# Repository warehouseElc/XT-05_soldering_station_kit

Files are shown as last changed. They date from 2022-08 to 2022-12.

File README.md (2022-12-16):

# XT-05 Soldering station kit
5 in 1 Soldering Rework Station "NOT Unisolder"

<p align="center">
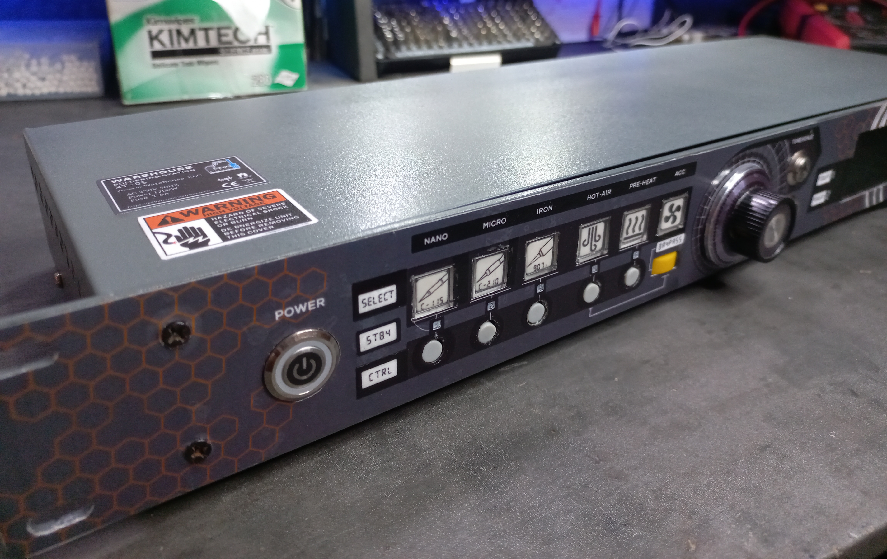
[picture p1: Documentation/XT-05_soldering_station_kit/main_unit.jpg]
  
</p> 

This project come for DIYers to make a good and reliable soldering station kit.
it works as independent controller, 
that's mean you can't swap the tip each other like unisolder cause it doesn't have a tip preset.
this come to much complexity for cable management, since i design it to be fully modular.
so... no solder required to disassamble whole unit.
all firmware not originaly made by me, but it's a lot of effort to modded and bugfixes.
if you want to copy or modified any of this resource, 
please let me know the result of your work.
this controller is still upgradable, but i dont have enough time to made this full of feature.

<p align="center">
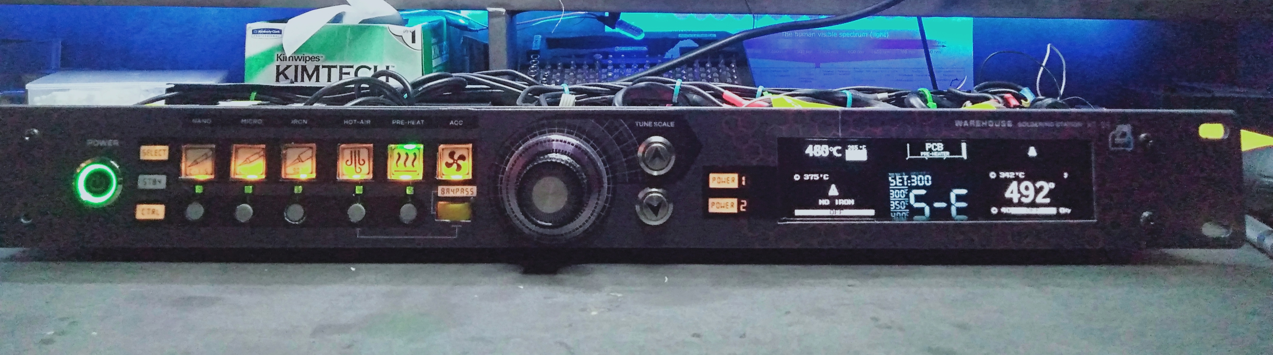
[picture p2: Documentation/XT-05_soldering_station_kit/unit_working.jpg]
  
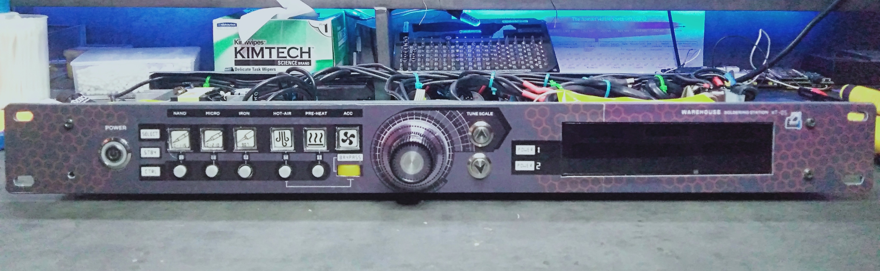
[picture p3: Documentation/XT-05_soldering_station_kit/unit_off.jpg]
  
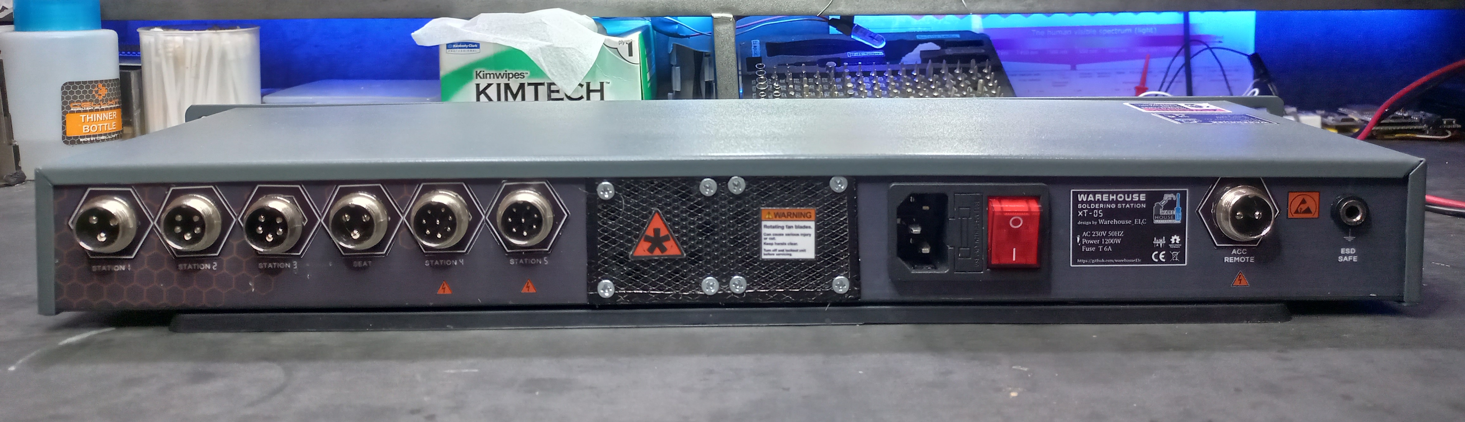
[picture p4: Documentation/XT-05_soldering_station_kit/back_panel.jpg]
  
</p> 

# Main Unit :
  * This unit controlled by atmega328p mount at FrontPanel board, it use I/O to select which controller you wanna uses and activated independent optocoupler for each controller and each signal.
  * ACC remote to turn on acc like fume extractor or etc by push a software latch button.
  * it's also come with one encoder and 2 button to operate the controller.
  * the CTRL switch operated directly to main controller power.
  * when push up & down button at the same time it will lock the I/O.
  * after 2 hour at Lock mode the unit goes to stby mode by switch off the relay main 5v & 12v , as indicator STBY turn green.
  * baypass mode working just for Hotair station.
  * an ESD plug was separated by main groung / AC earth socket.
    
<p align="center">
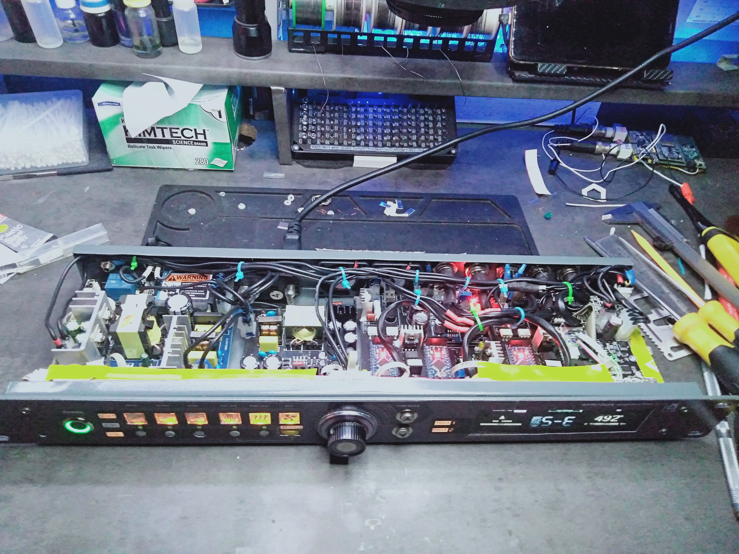
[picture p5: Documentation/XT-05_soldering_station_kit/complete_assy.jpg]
  
</p> 

<p align="center">
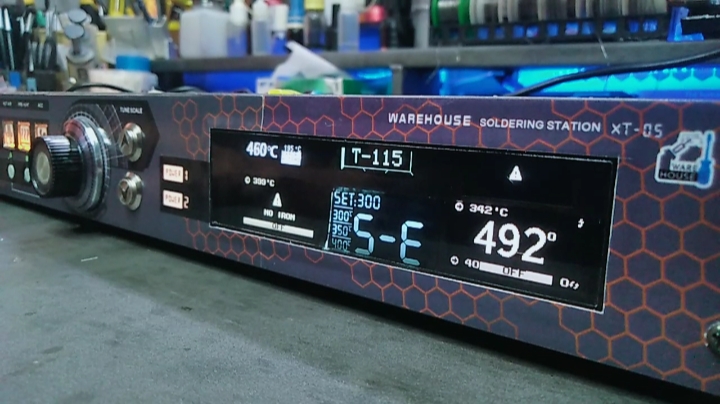
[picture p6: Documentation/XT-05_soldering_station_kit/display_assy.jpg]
  
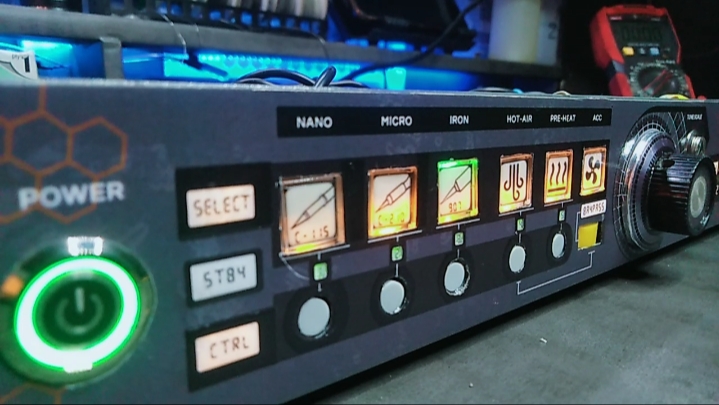
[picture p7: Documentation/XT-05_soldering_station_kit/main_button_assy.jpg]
  
</p> 

# This controller contains :

1. Nano solder NT-115.
   this controller use stm32f030f4 work at max 18v supply but the tip it self consume just 15w at 9v.
   i used 12v supply for this and calibrated it for chinese tip. if you want to use jbc original or diffrent vendor you just need re-calibrated it.
     
     Feature : 
     
       * can be use with any c-115 handle or tips.
       * sleep seat.
       * stable & fast respond time.
       * small PCB dimension.
       * less component
       * voltage supply, 3v3 & temp measurment.
       * calibrated menu.
       * error hi/lo-Temp, hi/lo-volt detection.
       
     Known Bug :
       
       * No buzzer/bepper
       * input supply must stable & avoid get voltage spike.
       * using medium-high cost & almost at rare status by now of component.
       * "dont cut" any 3v3 input since it use low-side mosfet it will directly supply 12v to the tip if 3v3 not coming.
       * need some protection if 12v on standby but 3v3 not coming.
       * encoder issue with some incompatible devices.
       * open 3v coming from the seat need more attention. "dont swap with Microsolder seat" 
       
2. Micro solder T-210.
   This controller still use Chinese GVM stc32. in future we can adapt NT-115 controller work for c-210 tip, but !!!
   i need more time to fix a bug and test it.
       
      Feature :
       
        * do i need to explain it ? i dont thing so.

3. iron solder hakko 9series.
    This controller use atmega328p (promini), and run at DC 24v very smoothly.
      
      Feature :
      
        * Tune & Calibrated Menu
        * error screen.
        * easy to use and interactive display.
        * isolated to main power.
        
      Known Bug :
      
        * hard to calibrate cause by slow reading.
        * auto sleep sometimes not working.
        * noisy at heater when start up.
        * no preset temp.
        
4. Hotair 858D.
    This controller use atmega328p (promini), with 700w 220v heater element.
      
      Feature :
      
        * Tune & Calibrated Menu
        * error screen.
        * easy to use and interactive display.
        * add bypass mode to active cool air.
        * isolated to main power
        
      Known Bug :
      
        * hard to calibrate cause by slow reading.
        * seat sleep is lag by 3second.
        * sometimes display get stuck.
        * no preset temp.
        
5. Pre-heater.
   This controller use atmega328p (promini), with 200w/400w 220v heater element.
   (based on Hotair station firmware).
   
      Feature :
      
        * Tune & Calibrated Menu
        * error screen.
        * easy to use and interactive display.
        * isolated to main power

      Known Bug :
      
        * hard to calibrate cause by slow reading.
        * very slow respond.
        * no preset temp.

# Technical Image.
<p align="center">
  hover text
</p> 
<p align="center">
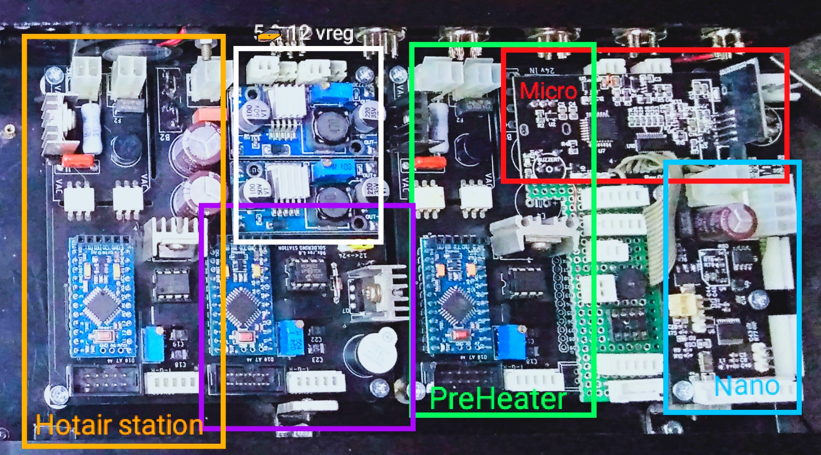
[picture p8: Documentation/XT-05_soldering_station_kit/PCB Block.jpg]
  
</p> 
<p align="center">
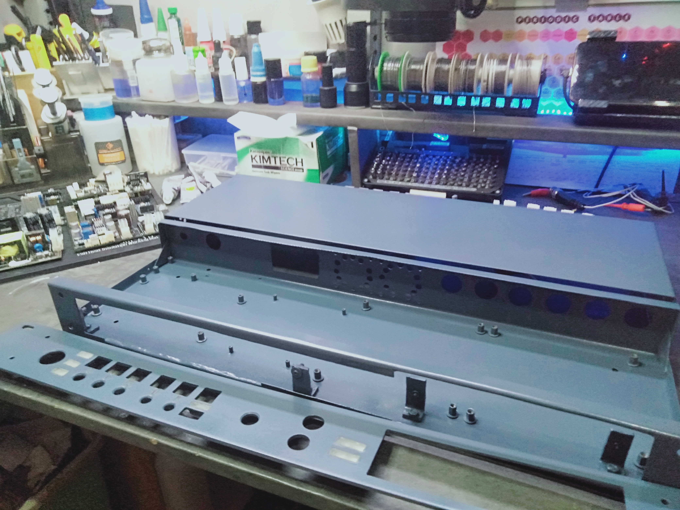
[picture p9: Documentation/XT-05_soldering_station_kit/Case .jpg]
  
</p> 
<p align="center">
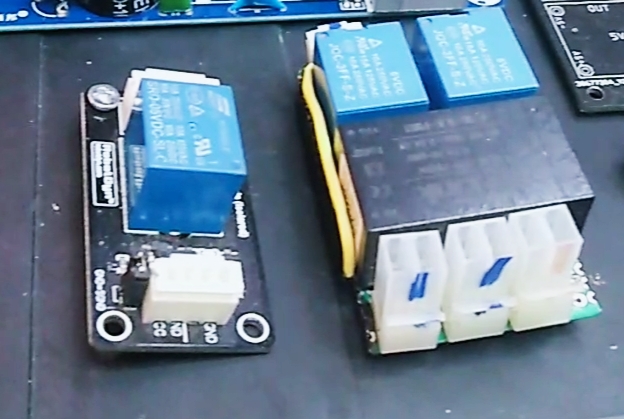
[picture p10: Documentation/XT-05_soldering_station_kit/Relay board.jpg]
  
</p> 
<p align="center">
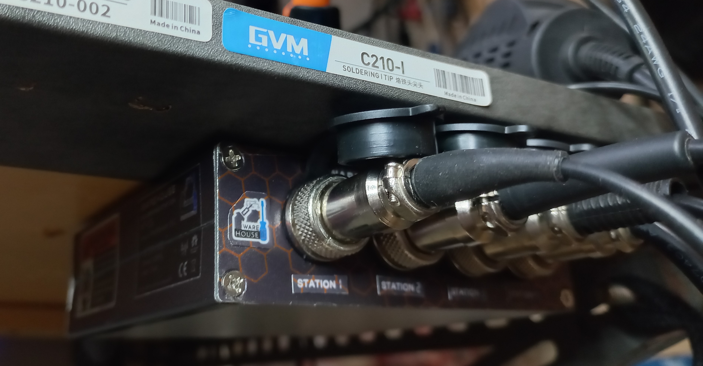
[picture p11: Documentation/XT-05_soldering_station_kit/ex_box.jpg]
  
</p> 

# Test Method :
  * it was 2 years testing by daily workflow until now no magic smoke no fire and no overheat.
  * all controller was test individual function without problem.
  * under heavy load still no problem.
  * unstable main VAC doesn't cause any issue.
  * working almost at 30c room temp no aircond everyday use.
  * standby more than 5 hour everyday.

# Progress on 2023 :
  * get some data by measure at maximum load
  * testing c210 on nano controller.
  * hardware & software bug fixes.
  * make some improvement.
  * added more protection.

# ChangeLog : 

  (2022)
  Firmware 9series v.2.1 Hotair v.1.5 PreHeater v.1.0 (Board v4.0) Nanosolder v.1.2 (Board v.1.1) F.panel v.1.2.1 (Board v.1.4.0) 
  
    * Put all controller in a 1u case.
    * add two extra button as simulated encoder output @10ms using FP_MCU.
    * using 2 PSU, 24v for iron,hotair,Preheater, 12v for nano & micro.
    * output can be use with extention box or just plug to main unit.
    * modified some powerline for controlling using FP_MCU.
        * 2 Relay add to main 220v control directly with power button
        * add relay module for ACC remote.
        * 2 Relay add for 5vreg & 12v main.
   
  (2021)
  Firmware 9series v.2.1 Hotair v.1.5 (Board Version 4.0) 
  
    * change component to SMD as possible
    * SH1106 Oled 1.3" Used For Display
    * Removing class PIDscreen for Hot Air to free some memory
    * Protection on Board
    * thermocouple / Thermoresistor Select on board
    * Fan 24/12volt select on board
    * Custom Front Panel for operated just only 1 encoder, I/O via IDC Socket

# Resource :
  This Project is Upgrade Version from Original.
   * Iron : https://create.arduino.cc/projecthub/sfrwmaker/soldering-iron-controller-for-hakko-907-v-2-fc75d7
   * Nano : https://github.com/Winkelkatze/jbc_nano_solder
   * Hotair & Preheater : https://www.hackster.io/makerbr555/diy-smd-rework-station-28b6f5

# first test of Board v3.0
https://www.youtube.com/watch?v=hSPyxu3pc1E

# first test of Board v4.0
https://youtu.be/PgkWCMdGw-8

# first test of full build (New Firmware)
coming soon...

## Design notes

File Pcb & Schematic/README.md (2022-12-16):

# PCB design status. 
  * PCB v.4.0 ready to use new firmware.
  * PCB v.4.0 can use also for preheater firmware.
  * PCB Front panel & nano not yet updated "need fix & redesign"

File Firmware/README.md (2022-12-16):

# Firmware info
  * Iron & hotair station use atmega328p 5v 16mhz.
  * Front Panel use atmega328p 3v 8mhz.
  * display SH1106 128x64 only for hotair & iron.
  * display SD1306 128x32 only for PreHeater & Front panel.
  * Please don't change any heater pinout, PID use it.

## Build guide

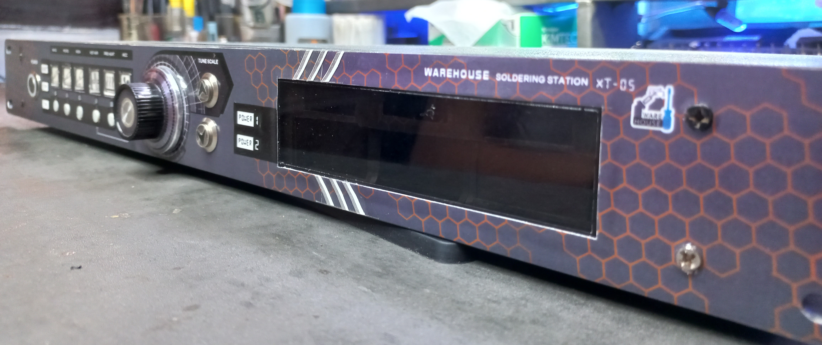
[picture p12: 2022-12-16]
Documentation/XT-05_soldering_station_kit/lcd_panel.jpg

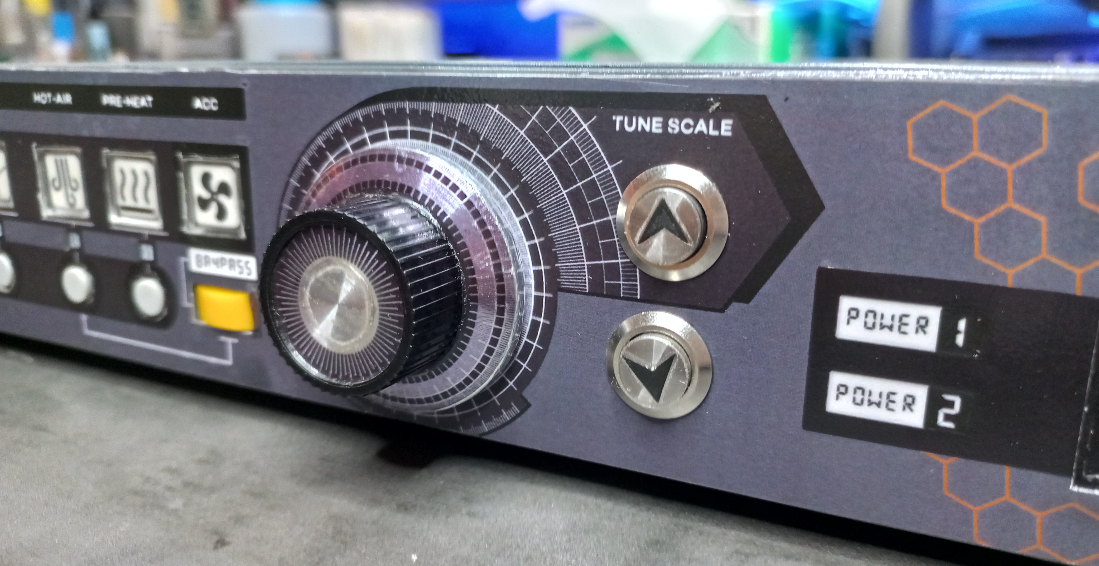
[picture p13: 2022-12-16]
Documentation/XT-05_soldering_station_kit/control.jpg

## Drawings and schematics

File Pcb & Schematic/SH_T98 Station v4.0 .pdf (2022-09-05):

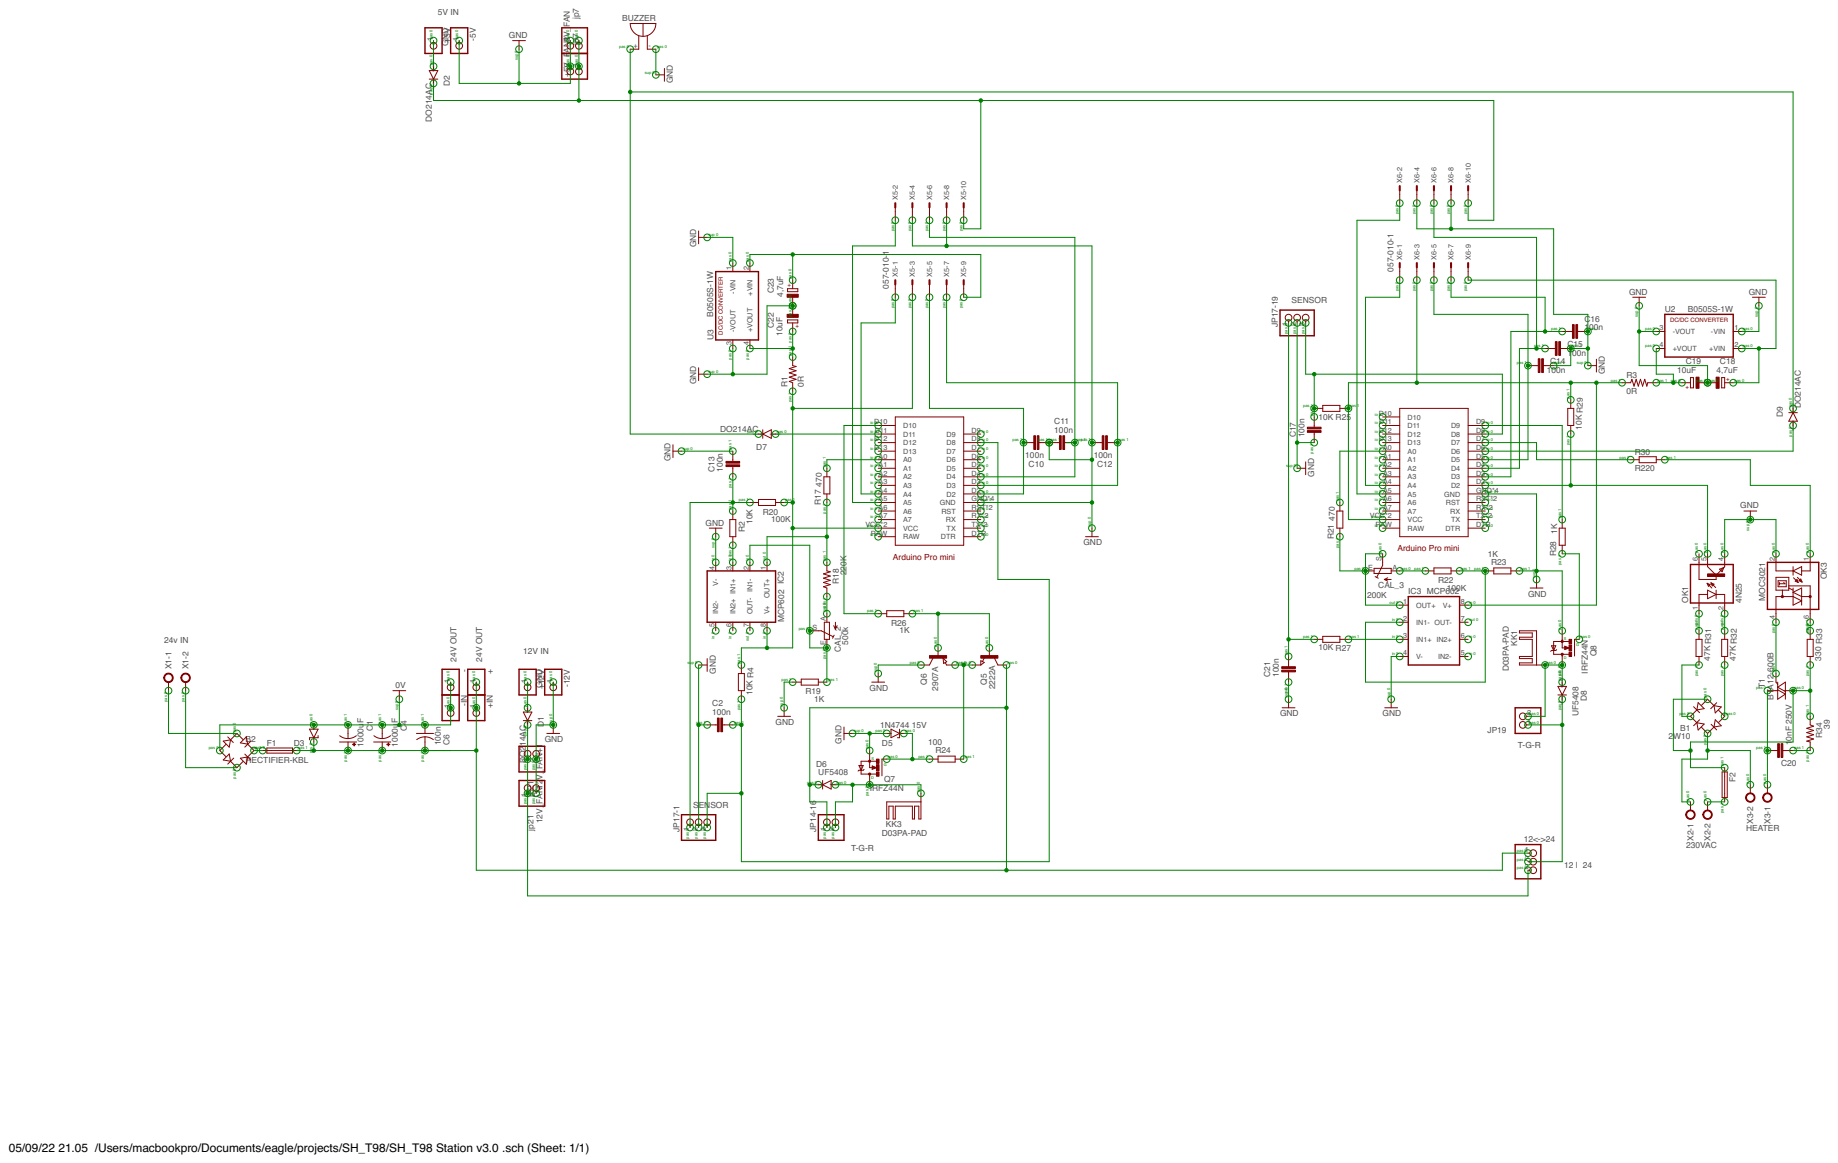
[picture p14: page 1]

pas 0 pas 0

pas 1 pas 1 pas 0 pas 0

pas 0 pas 0 pas 1 pas 1

pas 1 pas 1

05/09/22 21.05 /Users/macbookpro/Documents/eagle/projects/SH_T98/SH_T98 Station v3.0 .sch (Sheet: 1/1)

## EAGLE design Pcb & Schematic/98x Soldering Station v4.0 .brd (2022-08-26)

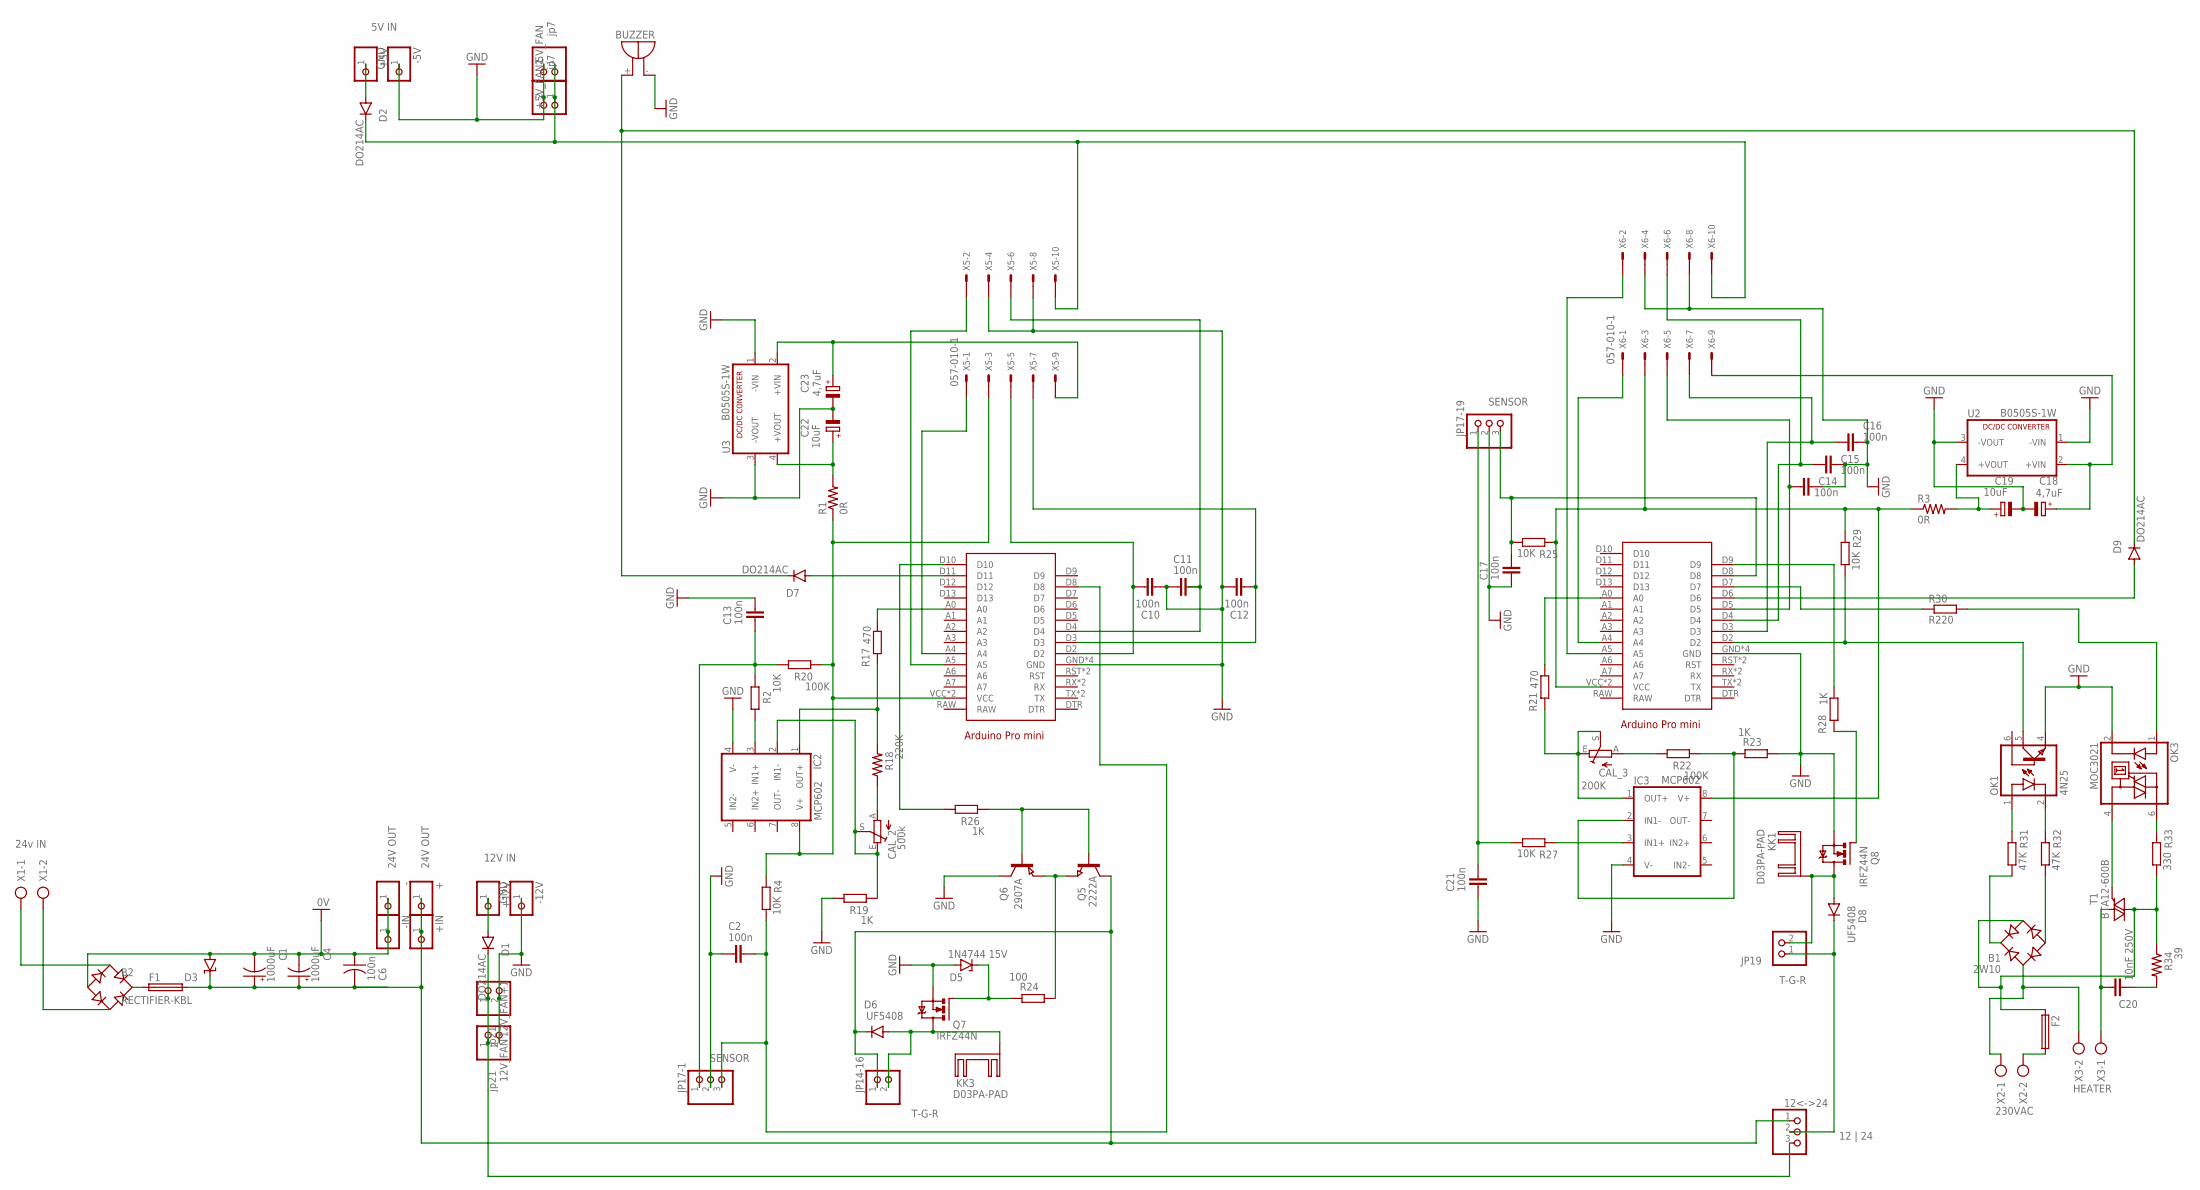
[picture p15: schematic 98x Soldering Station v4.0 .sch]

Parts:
5V_FAN: jp7; 1X02
12<->24: 12 | 24; 1X03
12V_FAN, 12V_FAN+1: jp21; 1X02
+: 24V OUT; 1X01
+5V: 5V IN; 1X01
+5V_FAN1: jp7; 1X02
+12V: 12V IN; 1X01
+IN: 24V OUT; 1X01
-, -5V, -12V: GND; 1X01
-IN: GND; 1X01
ARDUINO2: 907 solder; ARDUINO_PRO_MINI
ARDUINO3: HotAir; ARDUINO_PRO_MINI
B1: 2W10; RB1A
B2: RECTIFIER-KBL; KBL
BUZZER: BUZZER; F/TMB
C1, C4: 1000uF; E5-13
C2, C10, C11, C12, C13, C14, C15, C16, C17, C21: 100n; C0805
C6: 100n; C1206K
C18, C23: 4,7uF; B/3528-21R
C19, C22: 10uF; B/3528-21R
C20: 10nF 250V; C10B4
CAL_2: 500k; S64W
CAL_3: 200K; S64W
D1, D2, D7, D9: DO214AC
D3: SUPPRESSOR-SMBJ; SMBJ
D5: 1N4744 15V; DO41Z10
D6, D8: UF5408; SMC
F1, F2: TE5
IC2, IC3: MCP602; DIL08
JP14-16, JP19: T-G-R; 1X02
JP17-1, JP17-19: SENSOR; 1X03
KK1, KK3: D03PA-PAD
OK1: 4N25; DIL06
OK3: MOC3021; DIL06
Q5: 2222A; SOT23
Q6: 2907A; SOT23
Q7, Q8: IRFZ44N; TO220BV
R1, R3: 0R; M0805
R2, R4, R25, R27, R29: 10K; R0805
R17, R21: 470; R0805
R18: 220K; R0805
R19, R23, R26, R28: 1K; R0805
R20, R22: 100K; R0805
R24: 100; R0805
R30: R220; R0805
R31, R32: 47K; M1206
R33: 330; M1206
R34: 39; 0411/15
T1: BTA12-600B; TO220BV
U2, U3: B0505S-1W; 4SIL
X1: 24v IN; AK500/2-H
X2: 230VAC; AK500/2-H
X3: HEATER; AK500/2-H
X5, X6: 057-010-1

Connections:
0V: -.1, -IN.1, B2.-, C1.-, C4.-, C6.1, D3.A
GND: 5V_FAN.2, 12V_FAN.2, 12V_FAN+1.2, +5V_FAN1.2, -5V.1, -12V.1, ARDUINO2.GND, ARDUINO2.GND@1 (GND), ARDUINO2.GND@2 (GND), ARDUINO2.GND@3 (GND), ARDUINO3.GND, ARDUINO3.GND@1 (GND), ARDUINO3.GND@2 (GND), ARDUINO3.GND@3 (GND), BUZZER.-, C2.2, C10.2, C11.2, C12.1, C13.1, C14.2, C15.2, C16.2, C17.2, C18.-, C19.-, C21.2, C22.-, C23.-, D5.A, IC2.4 (V-), IC3.4 (V-), JP17-1.2, JP17-19.2, OK1.4 (EMI), OK3.2 (C), Q6.3 (C), Q7.S, Q8.S, R19.1, R23.1, U2.1 (-VIN), U2.3 (-VOUT), U3.1 (-VIN), U3.3 (-VOUT), X5.4, X5.8, X6.4, X6.8
unnamed: D6.A, JP14-16.2, KK3.B, Q7.D
unnamed: B2.+, F1.1
unnamed: 12<->24.3, 12V_FAN.1, 12V_FAN+1.1, D1.C
unnamed: C22.+, R1.2, U3.4 (+VOUT)
unnamed: C19.+, R3.2, U2.4 (+VOUT)
unnamed: IC2.3 (IN1+), R2.1
unnamed: B2.AC2, X1.2
unnamed: B2.AC1, X1.1
unnamed: F2.2, X2.2
unnamed: +12V.1, D1.A
unnamed: +5V.1, D2.A
unnamed: ARDUINO2.D8, C2.1, JP17-1.3, R4.2
unnamed: 12<->24.1, +.1, +IN.1, C1.+, C4.+, C6.2, D3.C, D6.C, F1.2, JP14-16.1, Q5.3 (C)
unnamed: ARDUINO2.A4, X5.1
unnamed: ARDUINO2.A5, X5.2
unnamed: BUZZER.+, D7.C, D9.C
unnamed: ARDUINO3.D7, R30.2
unnamed: ARDUINO2.D3, C12.2, X5.7
unnamed: C23.+, U3.2 (+VIN), X5.9
unnamed: Q5.2 (E), Q6.2 (E), R24.1
unnamed: C18.+, U2.2 (+VIN), X6.9
unnamed: 12<->24.2, D8.C, JP19.1
unnamed: 5V_FAN.1, +5V_FAN1.1, D2.C, X5.10, X6.10
unnamed: IC2.1 (OUT+), R17.1, R18.2
unnamed: ARDUINO2.D2, C10.1, X5.5
unnamed: ARDUINO2.D4, C11.1, X5.6
unnamed: ARDUINO2.D11, D7.A
unnamed: ARDUINO2.A0, R17.2
unnamed: ARDUINO3.A0, R21.2
unnamed: CAL_2.A, R18.1
unnamed: CAL_2.E, CAL_2.S, IC2.2 (IN1-), R19.2
unnamed: CAL_3.E, CAL_3.S, IC3.1 (OUT+), R21.1
unnamed: C13.2, JP17-1.1, R2.2, R20.1
unnamed: ARDUINO2.D10, R26.1
unnamed: Q5.1 (B), Q6.1 (B), R26.2
unnamed: D5.C, Q7.G, R24.2
unnamed: CAL_3.A, R22.1
unnamed: ARDUINO3.D8, C17.1, JP17-19.3, R25.2
unnamed: ARDUINO3.D5, C14.1, X6.5
unnamed: ARDUINO3.D4, C15.1, X6.6
unnamed: ARDUINO3.D3, C16.1, X6.7
unnamed: ARDUINO3.A4, X6.1
unnamed: ARDUINO3.A5, X6.2
unnamed: ARDUINO3.D9, R28.2
unnamed: IC3.2 (IN1-), R22.2, R23.2
unnamed: IC3.3 (IN1+), R27.1
unnamed: C21.1, JP17-19.1, R27.2
unnamed: D8.A, JP19.2, KK1.B, Q8.D
unnamed: OK3.4 (A1), T1.G
unnamed: Q8.G, R28.1
unnamed: ARDUINO3.D2, OK1.5 (COL), R29.2
unnamed: ARDUINO3.D6, D9.A
unnamed: ARDUINO3.VCC, ARDUINO3.VCC@1 (VCC), IC3.8 (V+), R3.1, R25.1, R29.1, X6.3
unnamed: OK3.1 (A), R30.1
unnamed: OK3.6 (A2), R33.1
unnamed: B1.AC2, F2.1, R33.2, R34.1, T1.T2 (A2)
unnamed: OK1.2 (C), R32.1
unnamed: OK1.1 (A), R31.1
unnamed: B1.+, R31.2
unnamed: B1.-, R32.2
unnamed: C20.1, T1.T1 (A1), X3.1
unnamed: C20.2, R34.2
unnamed: B1.AC1, X2.1, X3.2
unnamed: ARDUINO2.VCC, ARDUINO2.VCC@1 (VCC), IC2.8 (V+), R1.1, R4.1, R20.2, X5.3

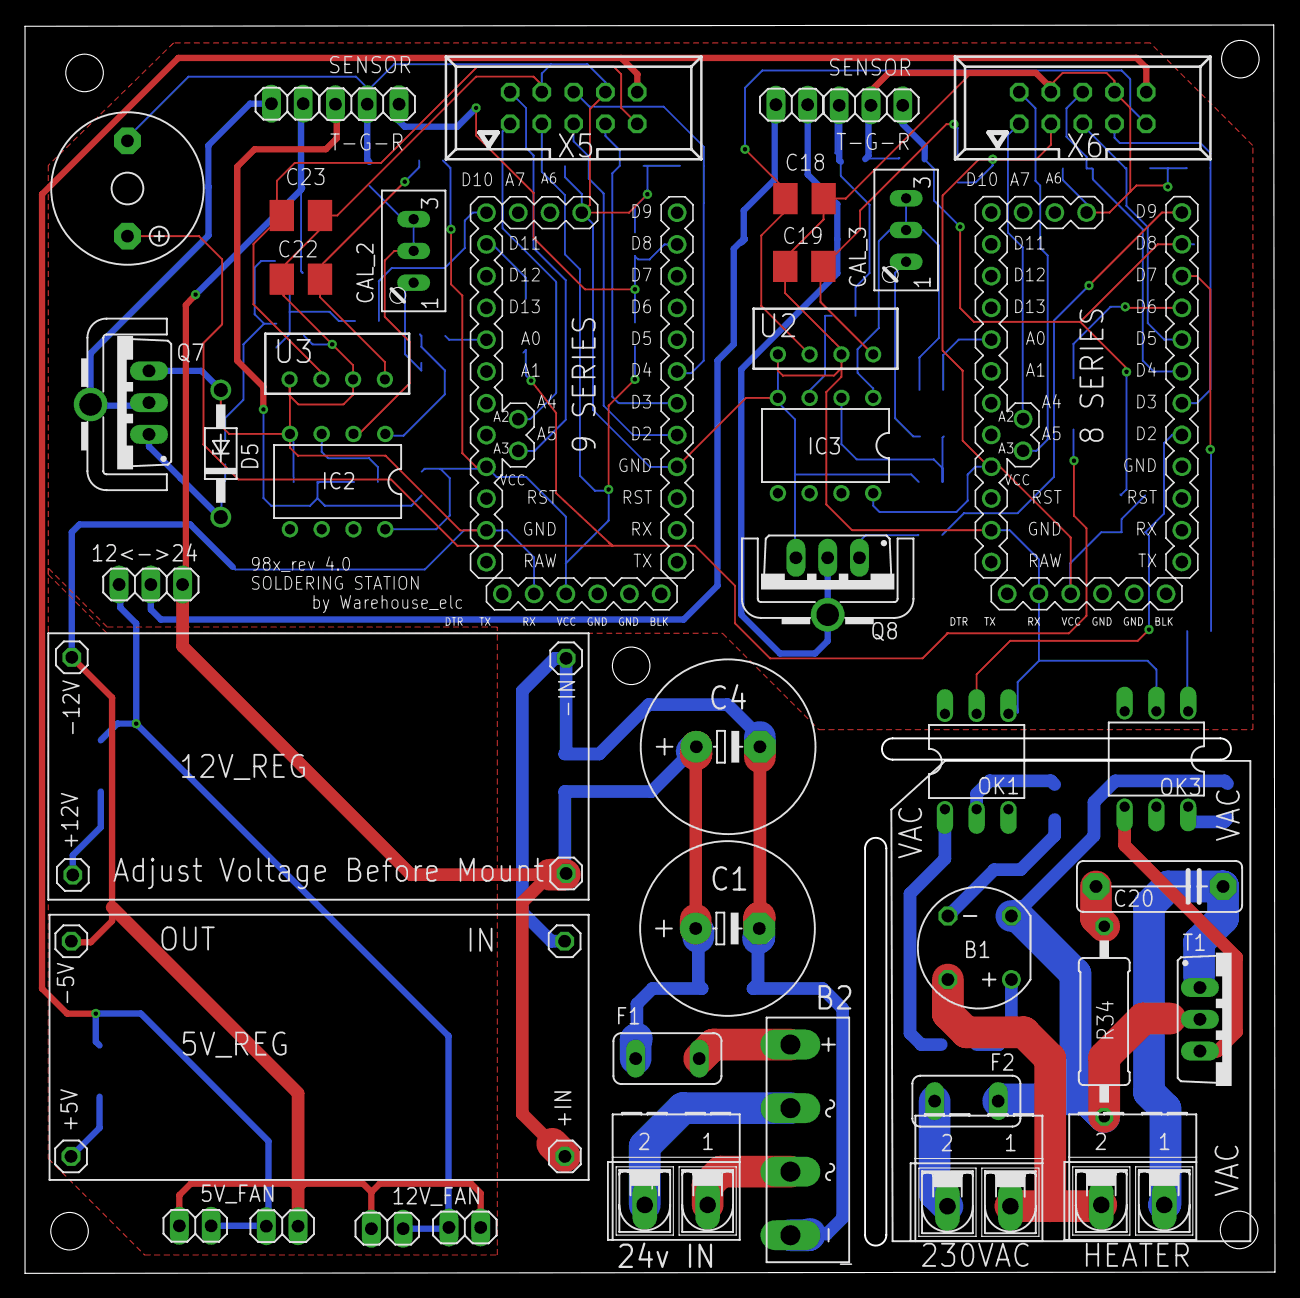
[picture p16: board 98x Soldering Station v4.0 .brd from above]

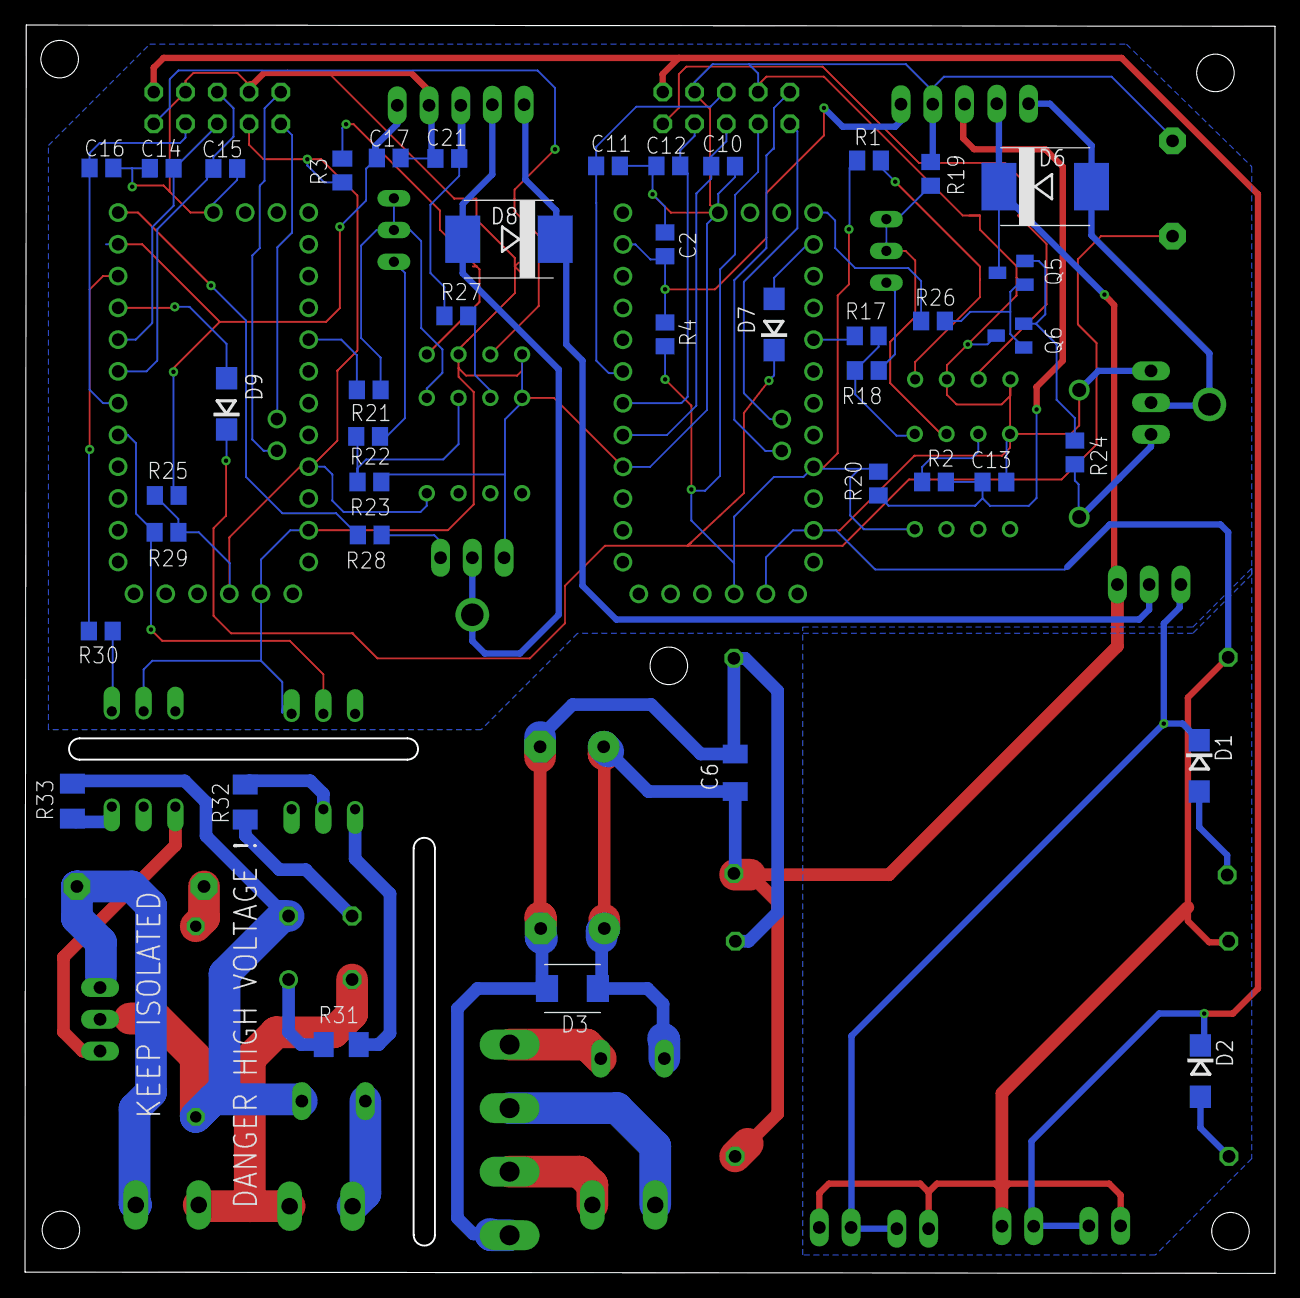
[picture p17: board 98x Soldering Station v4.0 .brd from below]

Board: 2 copper layers, 99.9 x 99.8 mm, 92 parts (41 on the bottom side), 66 nets.

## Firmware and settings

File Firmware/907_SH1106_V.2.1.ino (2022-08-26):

// Soldering Iron 907 mod by Warehouse_elc
// mods : OLED_SH1106 DISP I2C
// Firmware Version 2.1 
// Board Version 4.1
// Origin : v.2 https://create.arduino.cc/projecthub/sfrwmaker/soldering-iron-controller-for-hakko-907-v-2-fc75d7

#include <Arduino.h>
#include <EEPROM.h>
#include <U8x8lib.h> 

#ifdef U8X8_HAVE_HW_I2C
#include <Wire.h>
#endif

U8X8_SH1106_128X64_NONAME_HW_I2C u8x8(/* reset=*/ U8X8_PIN_NONE);

// Rotary encoder interface
const byte R_MAIN_PIN = 2;                    // Rotary Encoder main pin (right)
const byte R_SECD_PIN = 4;                   // Rotary Encoder second pin (left)
const byte R_BUTN_PIN = 3;                     // Rotary Encoder push button pin

const byte probePIN = A0;                 // Thermometer pin from soldering iron
const byte heaterPIN = 10;                      // The soldering iron heater pin
const byte buzzerPIN = 11;                  // The simple buzzer to make a noise

const uint16_t temp_minC = 200;     // Minimum temperature in degrees of celsius
const uint16_t temp_maxC = 480;     // Maximum temperature in degrees of celsius
const uint16_t temp_minF = (temp_minC * 9 + 32 * 5 + 2) / 5;
const uint16_t temp_maxF = (temp_maxC * 9 + 32 * 5 + 2) / 5;
const uint16_t temp_tip[3] = { 200, 300, 400 };

// The variables for Timer1 operations
volatile uint16_t tmr1_count; // The count to calculate the temperature check period
volatile bool iron_off; // Whether the IRON is switched off to check the temperature
const uint32_t check_period = 100;      // The IRON temperature check period, ms

//------------------------------------------ Configuration data ------------------------------------------------
/* Config record in the EEPROM has the following format:
 uint32_t ID                           each time increment by 1
 struct cfg                            config data, 8 bytes
 byte CRC                              the checksum
 */
struct cfg {
  uint32_t calibration; // The temperature calibration data for soldering IRON. (3 reference points: 200, 300, 400 Centegrees)
  uint16_t temp;   // The preset temperature of the IRON in the internal units
  byte off_timeout;    // The Automatic switch-off timeout in minutes [0 - 30]
  bool celsius;        // Temperature units: true - Celsius, false - Farenheit
};

class CONFIG {
public:
  CONFIG() {
    can_write = false;
    buffRecords = 0;
    rAddr = wAddr = 0;
    eLength = 0;
    nextRecID = 0;
    byte rs = sizeof(struct cfg) + 5;        // The total config record size
    // Select appropriate record size; The record size should be power of 2, i.e. 8, 16, 32, 64, ... bytes
    for (record_size = 8; record_size < rs; record_size <<= 1)
      ;
  }
  void init();bool load(void);
  void getConfig(struct cfg &Cfg);    // Copy config structure from this class
  void updateConfig(struct cfg &Cfg);   // Copy updated config into this class
  bool save(void);                   // Save current config copy to the EEPROM
  bool saveConfig(struct cfg &Cfg);    // write updated config into the EEPROM
  void clearAll(void);                              // Clean all EEPROM

protected:
  struct cfg Config;

private:
  bool readRecord(uint16_t addr, uint32_t &recID);bool can_write; // The flag indicates that data can be saved
  byte buffRecords;               // Number of the records in the outpt buffer
  uint16_t rAddr;         // Address of thecorrect record in EEPROM to be read
  uint16_t wAddr;           // Address in the EEPROM to start write new record
  uint16_t eLength;          // Length of the EEPROM, depends on arduino model
  uint32_t nextRecID;                               // next record ID
  byte record_size;                         // The size of one record in bytes
};

// Read the records until the last one, point wAddr (write address) after the last record
void CONFIG::init(void) {
  eLength = EEPROM.length();
  uint32_t recID;
  uint32_t minRecID = 0xffffffff;
  uint16_t minRecAddr = 0;
  uint32_t maxRecID = 0;
  uint16_t maxRecAddr = 0;
  byte records = 0;

  nextRecID = 0;

  // read all the records in the EEPROM find min and max record ID
  for (uint16_t addr = 0; addr < eLength; addr += record_size) {
    if (readRecord(addr, recID)) {
      ++records;
      if (minRecID > recID) {
        minRecID = recID;
        minRecAddr = addr;
      }
      if (maxRecID < recID) {
        maxRecID = recID;
        maxRecAddr = addr;
      }
    } else {
      break;
    }
  }

  if (records == 0) {
    wAddr = rAddr = 0;
    can_write = true;
    return;
  }

  rAddr = maxRecAddr;
  if (records < (eLength / record_size)) {           // The EEPROM is not full
    wAddr = rAddr + record_size;
    if (wAddr > eLength)
      wAddr = 0;
  } else {
    wAddr = minRecAddr;
  }
  can_write = true;
}

void CONFIG::getConfig(struct cfg &Cfg) {
  memcpy(&Cfg, &Config, sizeof(struct cfg));
}

void CONFIG::updateConfig(struct cfg &Cfg) {
  memcpy(&Config, &Cfg, sizeof(struct cfg));
}

bool CONFIG::saveConfig(struct cfg &Cfg) {
  updateConfig(Cfg);
  return save();                              // Save new data into the EEPROM
}

bool CONFIG::save(void) {
  if (!can_write)
    return can_write;
  if (nextRecID == 0)
    nextRecID = 1;

  uint16_t startWrite = wAddr;
  uint32_t nxt = nextRecID;
  byte summ = 0;
  for (byte i = 0; i < 4; ++i) {
    EEPROM.write(startWrite++, nxt & 0xff);
    summ <<= 2;
    summ += nxt;
    nxt >>= 8;
  }
  byte* p = (byte *) &Config;
  for (byte i = 0; i < sizeof(struct cfg); ++i) {
    summ <<= 2;
    summ += p[i];
    EEPROM.write(startWrite++, p[i]);
  }
  summ++;                                            // To avoid empty records
  EEPROM.write(wAddr + record_size - 1, summ);

  rAddr = wAddr;
  wAddr += record_size;
  if (wAddr > EEPROM.length())
    wAddr = 0;
  nextRecID++;                               // Get ready to write next record
  return true;
}

bool CONFIG::load(void) {
  bool is_valid = readRecord(rAddr, nextRecID);
  nextRecID++;
  return is_valid;
}

bool CONFIG::readRecord(uint16_t addr, uint32_t &recID) {
  byte Buff[record_size];

  for (byte i = 0; i < record_size; ++i)
    Buff[i] = EEPROM.read(addr + i);

  byte summ = 0;
  for (byte i = 0; i < sizeof(struct cfg) + 4; ++i) {

    summ <<= 2;
    summ += Buff[i];
  }
  summ++;                                            // To avoid empty fields
  if (summ == Buff[record_size - 1]) {                // Checksumm is correct
    uint32_t ts = 0;
    for (char i = 3; i >= 0; --i) {
      ts <<= 8;
      ts |= Buff[byte(i)];
    }
    recID = ts;
    memcpy(&Config, &Buff[4], sizeof(struct cfg));
    return true;
  }
  return false;
}

void CONFIG::clearAll(void) {
  for (int i = 0; i < eLength; ++i)
    EEPROM.write(i, 0);
  init();
  load();
}

//------------------------------------------ class IRON CONFIG -------------------------------------------------
class IRON_CFG: public CONFIG {
public:
  IRON_CFG() {
    current_tip = 0;
    t_tip[0] = t_tip[1] = t_tip[2] = 0;
    is_calibrated = false;
  }
  void init(void);bool isCelsius(void) {
    return Config.celsius;
  }
  bool isCold(uint16_t temp);        // Whether the IRON is temperature is low
  uint16_t tempPresetHuman(void); // The preset Temperature in the human readable units
  uint16_t tempPreset(void) {
    return Config.temp;
  }
  uint16_t human2temp(uint16_t temp); // Translate the human readable temperature into internal value
  uint16_t tempHuman(uint16_t temp); // Thanslate temperature from internal units to the human readable value (Celsius or Farenheit)
  byte selectTip(byte index);     // Select new tip, return selected tip index
  byte getOffTimeout(void) {
    return Config.off_timeout;
  }
  bool getTempUnits(void) {
    return Config.celsius;
  }
  bool savePresetTempHuman(uint16_t temp); // Save preset temperature in the human readable units
  bool savePresetTemp(uint16_t temp); // Save preset temperature in the internal units (convert it to the human readable units)
  void saveConfig(byte off, bool cels); // Save global configuration parameters
  void getCalibrationData(uint16_t& t_min, uint16_t& t_mid, uint16_t& t_max);
  void saveCalibrationData(uint16_t t_min, uint16_t t_mid, uint16_t t_max);
  void setDefaults(bool Write = false); // Set default parameter values if failed to load data from EEPROM
private:
  byte current_tip;                       // The current tip index
  bool is_calibrated;                   // whether the tip has calibrated data
  // t_tip[] - array of internal sensor readings of the current tip at reference temperatures,
  // defined in temp_tip[] global array
  uint16_t t_tip[3];
  const uint16_t def_tip[3] = { 587, 751, 916 }; // Default values of internal sensor readings at reference temperatures
  const uint16_t def_set = 653; // Default preset temperature in internal units
  const uint16_t ambient_temp = 0; // Ambient temperatire in the internal units
  const uint16_t ambient_tempC = 25;         // Ambient temperature in Celsius
};

void IRON_CFG::init(void) {
  CONFIG::init();
  if (!CONFIG::load())
    setDefaults(); // If failed to load the data from EEPROM, initialize the config data with default values
  uint32_t cd = Config.calibration;
  t_tip[0] = cd & 0x3FF;
  cd >>= 10; // 10 bits per calibration parameter, because the ADC readings are 10 bits
  t_tip[1] = cd & 0x3FF;
  cd >>= 10;
  t_tip[2] = cd & 0x3FF;
  // Check the tip calibration is correct
  if ((t_tip[0] >= t_tip[1]) || (t_tip[1] >= t_tip[2])) {
    setDefaults();
    for (byte i = 0; i < 3; ++i)
      t_tip[i] = def_tip[i];
  }
}

bool IRON_CFG::isCold(uint16_t temp) {
  return (temp < t_tip[0])
      && (map(temp, ambient_temp, t_tip[0], ambient_tempC, temp_tip[0])
          < 32);
}

uint16_t IRON_CFG::tempPresetHuman(void) {
  return tempHuman(Config.temp);
}

uint16_t IRON_CFG::human2temp(uint16_t t) { // Translate the human readable temperature into internal value
  uint16_t temp = t;
  if (!Config.celsius)
    temp = map(temp, temp_minF, temp_maxF, temp_minC, temp_maxC);
  if (t < temp_minC)
    t = temp_minC;
  if (t > temp_maxC)
    t = temp_maxC;
  if (t >= temp_tip[1])
    temp = map(t + 1, temp_tip[1], temp_tip[2], t_tip[1], t_tip[2]);
  else
    temp = map(t + 1, temp_tip[0], temp_tip[1], t_tip[0], t_tip[1]);

  for (byte i = 0; i < 10; ++i) {
    uint16_t tH = tempHuman(temp);
    if (tH <= t)
      break;
    --temp;
  }
  return temp;
}

// Thanslate temperature from internal units to the human readable value (Celsius or Farenheit)
uint16_t IRON_CFG::tempHuman(uint16_t temp) {
  uint16_t tempH = 0;
  if (temp < ambient_temp) {
    tempH = ambient_tempC;
  } else if (temp < t_tip[0]) {
    tempH = map(temp, ambient_temp, t_tip[0], ambient_tempC, temp_tip[0]);
  } else if (temp >= t_tip[1]) {
    tempH = map(temp, t_tip[1], t_tip[2], temp_tip[1], temp_tip[2]);
  } else {
    tempH = map(temp, t_tip[0], t_tip[1], temp_tip[0], temp_tip[1]);
  }
  if (!Config.celsius)
    tempH = map(tempH, temp_minC, temp_maxC, temp_minF, temp_maxF);
  return tempH;
}

bool IRON_CFG::savePresetTempHuman(uint16_t temp) {
  Config.temp = human2temp(temp);
  return CONFIG::save();
}

bool IRON_CFG::savePresetTemp(uint16_t temp) {
  Config.temp = temp;
  return CONFIG::save();
}

void IRON_CFG::saveConfig(byte off, bool cels) {
  if (off > 30)
    off = 0;
  Config.off_timeout = off;
  Config.celsius = cels;
  CONFIG::save();                             // Save new data into the EEPROM
}

void IRON_CFG::getCalibrationData(uint16_t& t_min, uint16_t& t_mid,
    uint16_t& t_max) {
  t_min = t_tip[0];
  t_mid = t_tip[1];
  t_max = t_tip[2];
}

void IRON_CFG::saveCalibrationData(uint16_t t_min, uint16_t t_mid,
    uint16_t t_max) {
  uint32_t cd = t_max & 0x3FF;
  cd <<= 10; // Pack tip calibration data in one 32-bit word: 10-bits per value
  cd |= t_mid & 0x3FF;
  cd <<= 10;
  cd |= t_min;

  Config.calibration = cd;
  t_tip[0] = t_min;
  t_tip[2] = t_mid;
  t_tip[2] = t_max;
}

void IRON_CFG::setDefaults(bool Write) {
  uint32_t c = def_tip[2] & 0x3FF;
  c <<= 10;
  c |= def_tip[1] & 0x3FF;
  c <<= 10;
  c |= def_tip[0] & 0x3FF;
  Config.calibration = c;
  Config.temp = def_set;
  Config.off_timeout = 0;   // Default autometic switch-off timeout (disabled)
  Config.celsius = true;                    // Default use celsius
  if (Write) {
    CONFIG::clearAll();
    CONFIG::save();
  }
}

//------------------------------------------ class BUZZER ------------------------------------------------------
class BUZZER {
public:
  BUZZER(byte buzzerP) {
    buzzer_pin = buzzerP;
  }
  void init(void);
  void shortBeep(void) {
    tone(buzzerPIN, 3520, 160);
  }
  void lowBeep(void) {
    tone(buzzerPIN, 880, 160);
  }
  void doubleBeep(void) {
    tone(buzzerPIN, 3520, 160);
    delay(300);
    tone(buzzerPIN, 3520, 160);
  }
  void failedBeep(void) {
    tone(buzzerPIN, 3520, 160);
    delay(170);
    tone(buzzerPIN, 880, 250);
    delay(260);
    tone(buzzerPIN, 3520, 160);
  }
private:
  byte buzzer_pin;
};

void BUZZER::init(void) {
  pinMode(buzzer_pin, OUTPUT);
  noTone(buzzer_pin);
}

//------------------------------------------ class BUTTON ------------------------------------------------------
class BUTTON {
public:
  BUTTON(byte ButtonPIN, unsigned int timeout_ms = 3000) {
    pt = tickTime = 0;
    buttonPIN = ButtonPIN;
    overPress = timeout_ms;
  }
  void init(void) {
    pinMode(buttonPIN, INPUT_PULLUP);
  }
  void setTimeout(uint16_t timeout_ms = 3000) {
    overPress = timeout_ms;
  }
  byte intButtonStatus(void) {
    byte m = mode;
    mode = 0;
    return m;
  }
  void cnangeINTR(void);
  byte buttonCheck(void);bool buttonTick(void);
private:
  volatile byte mode; // The button mode: 0 - not pressed, 1 - pressed, 2 - long pressed
  uint16_t overPress;          // Maxumum time in ms the button can be pressed
  volatile uint32_t pt; // Time in ms when the button was pressed (press time)
  uint32_t tickTime;            // The time in ms when the button Tick was set
  byte buttonPIN;                // The pin number connected to the button
  const uint16_t tickTimeout = 200; // Period of button tick, while tha button is pressed
  const uint16_t shortPress = 900; // If the button was pressed less that this timeout, we assume the short button press
};

void BUTTON::cnangeINTR(void) { // Interrupt function, called when the button status changed

  bool keyUp = digitalRead(buttonPIN);
  unsigned long now_t = millis();
  if (!keyUp) {                                 // The button has been pressed
    if ((pt == 0) || (now_t - pt > overPress))
      pt = now_t;
  } else {
    if (pt > 0) {
      if ((now_t - pt) < shortPress)
        mode = 1;  // short press
      else
        mode = 2;                          // long press
      pt = 0;
    }
  }
}

byte BUTTON::buttonCheck(void) { // Check the button state, called each time in the main loop

  mode = 0;
  bool keyUp = digitalRead(buttonPIN); // Read the current state of the button
  uint32_t now_t = millis();
  if (!keyUp) {                                 // The button is pressed
    if ((pt == 0) || (now_t - pt > overPress))
      pt = now_t;
  } else {
    if (pt == 0)
      return 0;
    if ((now_t - pt) > shortPress)              // Long press
      mode = 2;
    else
      mode = 1;
    pt = 0;
  }
  return mode;
}

bool BUTTON::buttonTick(void) { // When the button pressed for a while, generate periodical ticks

  bool keyUp = digitalRead(buttonPIN); // Read the current state of the button
  uint32_t now_t = millis();
  if (!keyUp && (now_t - pt > shortPress)) { // The button have been pressed for a while
    if (now_t - tickTime > tickTimeout) {
      tickTime = now_t;
      return (pt != 0);
    }
  } else {
    if (pt == 0)
      return false;
    tickTime = 0;
  }
  return false;
}

//------------------------------------------ class ENCODER ------------------------------------------------------
class ENCODER {
public:
  ENCODER(byte aPIN, byte bPIN, int16_t initPos = 0) {
    pt = 0;
    mPIN = aPIN;
    sPIN = bPIN;
    pos = initPos;
    min_pos = -32767;
    max_pos = 32766;
    channelB = false;
    increment = 1;
    changed = 0;
    is_looped = false;
  }
  void init(void) {
    pinMode(mPIN, INPUT_PULLUP);
    pinMode(sPIN, INPUT_PULLUP);
  }
  void set_increment(byte inc) {
    increment = inc;
  }
  byte get_increment(void) {
    return increment;
  }
  int16_t read(void) {
    return pos;
  }
  void reset(int16_t initPos, int16_t low, int16_t upp, byte inc = 1,
      byte fast_inc = 0, bool looped = false);bool write(int16_t initPos);
  void cnangeINTR(void);
private:
  int32_t min_pos, max_pos;
  volatile uint32_t pt;             // Time in ms when the encoder was rotaded
  volatile uint32_t changed;          // Time in ms when the value was changed
  volatile bool channelB;
  volatile int16_t pos;                      // Encoder current position
  byte mPIN, sPIN; // The pin numbers connected to the main channel and to the socondary channel
  bool is_looped;                // Whether the encoder is looped
  byte increment;       // The value to add or substract for each encoder tick
  byte fast_increment;     // The value to change encoder when in runs quickly
  const uint16_t fast_timeout = 300;   // Time in ms to change encodeq quickly
  const uint16_t overPress = 1000;
};

bool ENCODER::write(int16_t initPos) {
  if ((initPos >= min_pos) && (initPos <= max_pos)) {
    pos = initPos;
    return true;
  }
  return false;
}

void ENCODER::reset(int16_t initPos, int16_t low, int16_t upp, byte inc,
    byte fast_inc, bool looped) {
  min_pos = low;
  max_pos = upp;
  if (!write(initPos))
    initPos = min_pos;
  increment = fast_increment = inc;
  if (fast_inc > increment)
    fast_increment = fast_inc;
  is_looped = looped;
}

void ENCODER::cnangeINTR(void) { // Interrupt function, called when the channel A of encoder changed

  bool rUp = digitalRead(mPIN);
  unsigned long now_t = millis();
  if (!rUp) {                              // The channel A has been "pressed"
    if ((pt == 0) || (now_t - pt > overPress)) {
      pt = now_t;
      channelB = digitalRead(sPIN);
    }
  } else {
    if (pt > 0) {
      byte inc = increment;
      if ((now_t - pt) < overPress) {
        if ((now_t - changed) < fast_timeout)
          inc = fast_increment;
        changed = now_t;
        if (channelB)
          pos -= inc;
        else
          pos += inc;
        if (pos > max_pos) {
          if (is_looped)
            pos = min_pos;
          else
            pos = max_pos;
        }
        if (pos < min_pos) {
          if (is_looped)
            pos = max_pos;
          else
            pos = min_pos;
        }
      }
      pt = 0;
    }
  }
}

//------------------------------------------ class lcd DSPLay for soldering iron -----------------------------
class DSPL: protected U8X8_SH1106_128X64_NONAME_HW_I2C {
public:
  DSPL(void) :
      U8X8_SH1106_128X64_NONAME_HW_I2C () {
  }
  void init(void);
  void clear(void) {
   U8X8::clearDisplay();   

  }
  void tSet(uint16_t t, bool celsuis);        // Show the temperature set
  void tCurr(uint16_t t, bool celsius);        // Show The current temperature
  void pSet(byte p);                          // Show the power set
  void timeToOff(byte sec);         // Show the time to automatic off the iron
  void msgNoIron(void);                       // Show 'No iron' message
  void msgReady(void);                        // Show 'Ready' message
  void msgWorking(void);                      // Show 'Working' message
  void msgOn(void);                           // Show 'On' message
  void msgOff(void);                          // Show 'Off' message
  void msgCold(void);                         // Show 'Cold' message
  void msgFail(void);                         // Show 'Fail' message
  void msgTune(void);                         // Show 'Tune' message
  void msgCelsius(void);                      // Show 'Cels.' message
  void msgFarneheit(void);                    // Show 'Faren.' message
  void msgDefault();    // Show 'default' message (load default configuratuin)
  void msgCancel(void);                       // Show 'cancel' message
  void msgApply(void);                        // Show 'save message'
  void setupMode(byte mode, byte p = 0); // Show the configureation mode [0 - 2]
  void percent(byte Power);                   // Show the percentage
private:

};

void DSPL::init(void) {
  U8X8::begin(); 
}
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
void loop() {
  static int16_t old_pos = rotEncoder.read();
  iron.checkIron();       // Periodically check that the IRON works correctrly

  bool iron_on = iron.isOn();
  if ((pCurrentScreen == &wrkScr) && !iron_on) {  // the soldering iron failed
    pCurrentScreen = &errScr;
    pCurrentScreen->init();
  }

  SCREEN* nxt = pCurrentScreen->returnToMain();
  if (nxt != pCurrentScreen) {         // return to the main screen by timeout
    pCurrentScreen = nxt;
    pCurrentScreen->init();
  }

  byte bStatus = rotButton.intButtonStatus();
  switch (bStatus) {
  case 2:                                     // long press;
    nxt = pCurrentScreen->menu_long();
    if (nxt != pCurrentScreen) {
      pCurrentScreen = nxt;
      pCurrentScreen->init();
    } else {
      if (pCurrentScreen->isSetup())
        pCurrentScreen->resetTimeout();
    }
    break;
  case 1:                                     // short press
    nxt = pCurrentScreen->menu();
    if (nxt != pCurrentScreen) {
      pCurrentScreen = nxt;
      pCurrentScreen->init();
    } else {
      if (pCurrentScreen->isSetup())
        pCurrentScreen->resetTimeout();
    }
    break;
  case 0:                                     // Not pressed
  default:
    break;
  }

  int16_t pos = rotEncoder.read();
  if (old_pos != pos) {
    pCurrentScreen->rotaryValue(pos);
    old_pos = pos;
    if (pCurrentScreen->isSetup())
      pCurrentScreen->resetTimeout();
  }

  pCurrentScreen->show();
}

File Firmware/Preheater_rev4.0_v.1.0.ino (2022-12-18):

// Pre-Heater Reflow Plate 200w controller modded by Warehouse_elc
// Released Aug 26, 2022
// Firmware Version 1.0 (atMega328p 5v 16mhz)
// Board Version 4.0
// Based from https://www.hackster.io/makerbr555/diy-smd-rework-station-28b6f5

#include <avr/io.h>
#include <avr/interrupt.h>
#include <Arduino.h>

#include <EEPROM.h>
#include <U8x8lib.h> 
#include <CommonControls.h>

#ifdef U8X8_HAVE_HW_I2C
#include <Wire.h>
#endif

U8X8_SSD1306_128X32_UNIVISION_HW_I2C u8x8(/* reset=*/ U8X8_PIN_NONE, /* clock=*/ SCL, /* data=*/ SDA);

const uint16_t temp_minC       = 50;                                        // Minimum temperature the controller can check accurately
const uint16_t temp_maxC       = 260;                                       // Maximum possible temperature
const uint16_t temp_ambC       = 30;                                        // Average ambient temperature
const uint16_t temp_tip[3]     = {50, 150, 250};                            // Temperature reference points for calibration
const uint16_t min_working_fan = 30;                                        // Minimal possible fan speed

const uint8_t AC_SYNC_PIN      = 2;                                         // Outlet 220 v synchronization pin. Do not change!
const uint8_t HOT_GUN_PIN      = 7;                                         // Hot gun heater management pin
const uint8_t FAN_GUN_PIN      = 9;                                         // Hot gun fan management pin. Do not change! 
const uint8_t TEMP_GUN_PIN     = A0;                                        // Hot gun temperature checking pin

const uint8_t R_MAIN_PIN       = 3;                                         // Rotary encoder main pin. Do not change!
const uint8_t R_SECD_PIN       = 5;                                         // Rotary encoder secondary pin
const uint8_t R_BUTN_PIN       = 4;                                         // Rotary encoder button pin

const uint8_t REED_SW_PIN      = 8;                                         // Reed switch pin
const uint8_t BUZZER_PIN       = 6;                                         // Buzzer pin
const bool    BUZZER_ACTIVE    = true;                                      // Active buzzer beeps when +5v supplied to it

//------------------------------------------ Configuration data ------------------------------------------------
/* Config record in the EEPROM has the following format:
 * uint32_t ID                           each time increment by 1
 * struct cfg                            config data, 8 bytes
 * byte CRC                              the checksum
*/
struct cfg {
    uint32_t    calibration;                                                // Packed calibration data by three temperature points
    uint16_t    temp;                                                       // The preset temperature of the IRON in internal units
    uint8_t     fan;                                                        // The preset fan speed 0 - 255
    uint8_t     off_timeout;                                                // Automatic switch-off timeout
};

class CONFIG {
    public:
        CONFIG() {
            can_write     = false;
            buffRecords   = 0;
            rAddr = wAddr = 0;
            eLength       = 0;
            nextRecID     = 0;
            uint8_t rs = sizeof(struct cfg) + 5;                            // The total config record size
            for (record_size = 8; record_size < rs; record_size <<= 1);     // Select appropriate record size; The record size should be power of 2, i.e. 8, 16, 32, 64, ... bytes
        }
        void init();
        bool load(void);
        void getConfig(struct cfg &Cfg);                                    // Copy config structure from this class
        void updateConfig(struct cfg &Cfg);                                 // Copy updated config into this class
        bool save(void);                                                    // Save current config copy to the EEPROM
        bool saveConfig(struct cfg &Cfg);                                   // write updated config into the EEPROM

    protected:
        struct   cfg Config;

    private:
        bool     readRecord(uint16_t addr, uint32_t &recID);
        bool     can_write;                                                 // The flag indicates that data can be saved
        uint8_t  buffRecords;                                               // Number of the records in the outpt buffer
        uint16_t rAddr;                                                     // Address of thecorrect record in EEPROM to be read
        uint16_t wAddr;                                                     // Address in the EEPROM to start write new record
        uint16_t eLength;                                                   // Length of the EEPROM, depends on arduino model
        uint32_t nextRecID;                                                 // next record ID
        uint8_t  record_size;                                               // The size of one record in bytes
};

 
void CONFIG::init(void) {                                                   // Read the records until the last one, point wAddr (write address) after the last record
    eLength = EEPROM.length();
    uint32_t recID;
    uint32_t minRecID = 0xffffffff;
    uint16_t minRecAddr = 0;
    uint32_t maxRecID = 0;
    uint16_t maxRecAddr = 0;
    uint8_t  records = 0;

    nextRecID = 0;

    
    for (uint16_t addr = 0; addr < eLength; addr += record_size) {          // read all the records in the EEPROM find min and max record ID
        if (readRecord(addr, recID)) {
            ++records;
            if (minRecID > recID) {
                minRecID = recID;
                minRecAddr = addr;
            }
            if (maxRecID < recID) {
                maxRecID = recID;
                maxRecAddr = addr;
            }
        } else {
            break;
        }
    }

    if (records == 0) {
        wAddr = rAddr = 0;
        can_write = true;
        return;
    }

    rAddr = maxRecAddr;
    if (records < (eLength / record_size)) {                                // The EEPROM is not full
        wAddr = rAddr + record_size;
        if (wAddr > eLength) wAddr = 0;
    } else {
        wAddr = minRecAddr;
    }
    can_write = true;
}

void CONFIG::getConfig(struct cfg &Cfg) {
    memcpy(&Cfg, &Config, sizeof(struct cfg));
}

void CONFIG::updateConfig(struct cfg &Cfg) {
    memcpy(&Config, &Cfg, sizeof(struct cfg));
}

bool CONFIG::saveConfig(struct cfg &Cfg) {
    updateConfig(Cfg);
    return save();                                                          // Save new data into the EEPROM
}
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

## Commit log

2022-09-13 Update and rename Preheater_rev4.1v.1.6.ino to Preheater_rev4.1v.1.0.ino
2022-12-13 Create XT-05 soldering station kit
